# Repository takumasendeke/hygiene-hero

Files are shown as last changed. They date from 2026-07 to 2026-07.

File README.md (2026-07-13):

# Hygiene Hero 🫧
> "Making Clean Hands the Norm, Not the Exception"

Welcome to the official repository for **Hygiene Hero**, an interactive, behavior-driven embedded system designed to guide users through a proper 20-second handwashing routine recommended by WHO.

## Overview
Hand hygiene is a critical aspect of public health, yet global compliance rates remain incredibly low, with the average wash time sitting at just 6 seconds. Built as an open-source Electrical and Computer Engineering project at the University of Cape Town, Hygiene Hero tackles this behavioral shortfall. It utilizes multi-sensory feedback—including a visual countdown, animated graphics, and audio cues to encourage longer, proper handwashing and make the process engaging.

## Key Features
* **Touchless Activation:** Uses HC-SR04 ultrasonic sensors to monitor hand presence. 
* **Dynamic Visuals:** An ST7920 128x64 LCD plays custom, memory-optimized XBM animations directly from PROGMEM to save SRAM.
* **Clear Countdown:** A dual 7-segment display (driven by 74HC595 shift registers) provides an intuitive 20-second progress tracker.
* **Audio Nudges:** A DFPlayer Mini module plays background melodies and AI-generated vocal prompts over a UART interface.
* **Custom Enclosure:** A modular, 3D-printed housing designed in Onshape to protect the circuitry in a bathroom environment.

## Hardware Stack

| Component | Purpose |
| :--- | :--- |
| **Arduino Uno R3** | Master microcontroller orchestrating the state machine. |
| **ST7920 LCD (128x64)** | Renders handwashing animations and health facts via the U8g2 library. |
| **5161AS 7-Segment** | 2-digit display for the 20-second countdown. |
| **74HC595 Shift Registers** | Serial-to-parallel converters to drive the 7-segment display using minimal MCU pins. |
| **DFPlayer Mini + 8Ω Speaker** | Handles MP3 playback for background music and vocal cues. |
| **NE555D Timer** | Astable oscillator offloading the ultrasonic trigger pulse from the MCU. |
| **HC-SR04 / Tactile Button** | Inputs for proximity and soap detection. |

## Repository Structure

| Directory | Description |
| :--- | :--- |
| `/firmware` | Contains isolated subsystem prototypes and the final modular C++ source code (`src/` and `include/`). |
| `/hardware` | KiCad schematics, subcircuit experiments, and the final integrated PCB design. |
| `/enclosure` | CAD exports (STLs, STEPs) for the custom Bambu Lab 3D-printed housing. |
| `/docs` | Component datasheets, wiring diagrams, and project presentations. |

## Getting Started
1. Navigate to the `/firmware/prototypes` directory to view the isolated component tests for the display, audio, and sensors.
2. The final Object-Oriented system logic can be found in `/firmware/src/main.cpp`.
3. Ensure you have the `U8g2` and `DFRobotDFPlayerMini` libraries installed in your Arduino IDE or PlatformIO environment before compiling.

---
*Developed by Takudzwa Masendeke.*

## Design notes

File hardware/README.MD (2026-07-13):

# Hardware Design - Hygiene Hero 

Welcome to the hardware documentation for **Hygiene Hero**. This directory contains all Electronic Design Automation (EDA) files, chronicling the journey from initial proof-of-concept schematics to the final integrated Printed Circuit Board (PCB) ready for mass manufacturing.

## Hardware Architecture Overview
The Hygiene Hero hardware bridges standard microcontroller logic with custom analog and digital sub-systems. To optimize the Arduino Uno R3's (ATmega328P) processing load and pin count, the hardware specifically offloads tasks:
* **Hardware Triggering:** A 555 timer in astable mode continuously generates trigger pulses for the ultrasonic proximity sensors.
* **Serial-to-Parallel Conversion:** Daisy-chained 74HC595 shift registers drive the 2-digit 7-segment display using only 3 MCU pins.
* **Voltage Level Shifting:** A dedicated resistor network safely steps down the 5V TX logic to interface with the 3.3V RX line of the DFPlayer Mini.

## Directory Structure

| Directory | Description |
| :--- | :--- |
| `/main_board` | Contains the master KiCad project (`.pro`, `.sch`, `.kicad_pcb`). This is the final integrated custom PCB layout combining the MCU, audio, display, and sensor logic into a single, cohesive board. |
| `/subcircuits` | Holds the isolated schematics used during the breadboarding and prototyping phase (e.g., `Audio.kicad_sch`, `7 Seg Circuit.kicad_sch`, `Soap_water.kicad_sch`). These document the step-by-step engineering and debugging process. |
| `/production` | Contains the fabrication outputs required by PCB manufacturers. Includes Gerber files, NC Drill files, the Bill of Materials (BOM), and Component Placement Lists (CPL) for automated assembly. |

## Tools Used
* **EDA Software:** Designed and routed using [KiCad 10.0](https://www.kicad.org/).
* **Mechanical CAD:** The accompanying housing (found in the root `/enclosure` folder) was designed using Onshape.

## Viewing the Files
To open and edit the raw schematic and PCB files, you will need to install KiCad. Alternatively, PDF versions of the core schematics are provided within their respective folders for quick viewing without the EDA software.

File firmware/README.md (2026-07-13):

# Firmware - Hygiene Hero 

Welcome to the firmware documentation for **Hygiene Hero**. This directory houses the embedded C/C++ code that powers the system's state machine, audio handling, visual rendering, and sensor polling. 

## Software Architecture
The firmware for Hygiene Hero is built with a focus on memory optimization and modularity to operate efficiently on the 2KB SRAM constraint of the ATmega328P. 
* **Memory Management:** High-resolution display frames are converted to XBM format and stored entirely in Flash memory (`PROGMEM`) to prevent SRAM overflow.
* **Non-Blocking Logic:** The final system utilizes time-delta polling (`millis()`) rather than blocking `delay()` calls, allowing the MCU to multitask audio playback, display updates, and sensor reading simultaneously.
* **Object-Oriented Design:** The core logic is encapsulated into distinct C++ classes (`ShiftDisplay`, `AudioDeck`, `Sonar`) to ensure clean hardware abstraction and prevent variable scope conflicts.

## Directory Structure

| Directory | Description |
| :--- | :--- |
| `/prototypes` | Contains isolated "board bring-up" tests (e.g., `ultrasonic_test.ino`, `audio_Test.ino`). These standalone scripts were used to validate individual hardware subsystems and debug communication protocols prior to full system integration. |
| `/src` | Contains the final integrated C++ implementation files (`.cpp`), including the master state machine orchestrator (`main.cpp`). |
| `/include` | Contains the architectural blueprint headers (`.h`) for the OOP classes, defining the public interfaces and private hardware bindings. |

## Core Dependencies
To compile this firmware, ensure the following libraries are installed in your Arduino IDE or PlatformIO environment:
* **[U8g2](https://github.com/olikraus/u8g2):** For driving the ST7920 128x64 graphical display.
* **[DFRobotDFPlayerMini](https://github.com/DFRobot/DFRobotDFPlayerMini):** For UART control of the MP3 audio module.
* **SoftwareSerial:** Standard Arduino library used for virtual serial communication with the audio module.

## Compilation & Flashing
The final integrated code within `/src` is designed to be compiled using standard GCC toolchains or PlatformIO. If using the standard Arduino IDE, ensure the `.cpp` and `.h` files are located in a sketch folder named to match the primary `.ino` or `.cpp` file.

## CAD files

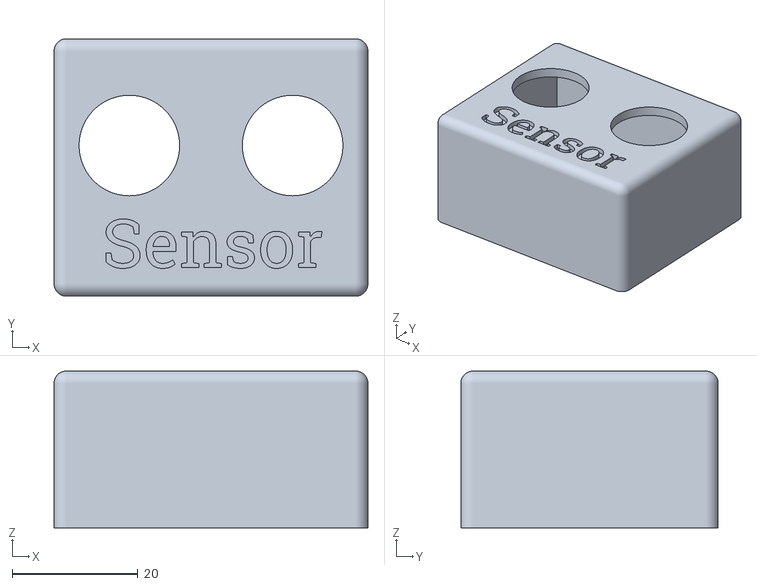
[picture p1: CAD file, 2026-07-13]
enclosure/CAD/sensor housing.stl
50.0 x 41.0 x 25.0

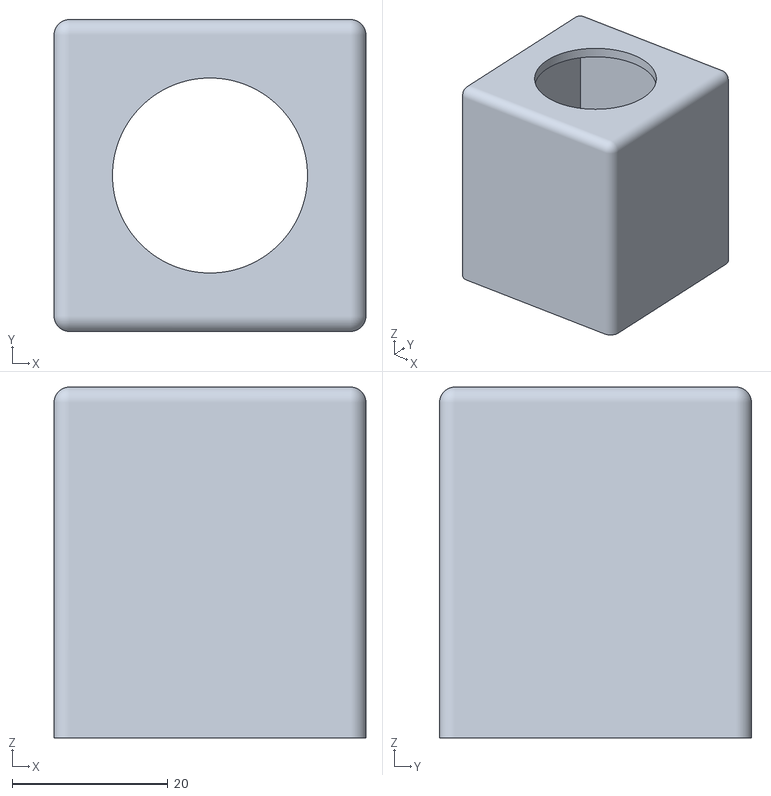
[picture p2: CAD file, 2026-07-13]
enclosure/CAD/button housing.stl
40.0 x 40.0 x 45.0

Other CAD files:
enclosure/3D print/Sensor & button housing.gcode.3mf

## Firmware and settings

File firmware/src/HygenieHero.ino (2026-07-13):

/*
Takudzwa Masendeke

This code is the main firmware for the Hygiene Hero Project.
It combines all the code from the prototyping to create the 
final system altogether.

HYGENIE HERO - v6.0

updates:
-added voice ques for actions
*/

#include "Components.h"
#include "Bitmaps.h"

// CONFIGURATION
const unsigned long IDLE_TRACK_MS  = 139000; // 2m 19s Song
const unsigned long SCRUB_MUSIC_MS = 25000; 
const unsigned long COME_BACK_MS   = 5000;  
const unsigned long ABANDON_TIMEOUT = 10000; 
const unsigned long SOAP_TIMEOUT    = 5000;  

// INSTANTIATE OBJECTS 
U8G2_ST7920_128X64_1_SW_SPI u8g2(U8G2_R0, 13, 11, 10, 12);
ShiftDisplay timer(5, 6, 7);   
AudioDeck voice(8, 9);         
Sonar hands(3, 4, 20.0);       

const uint8_t BTN_PIN = 2;

// VARIABLES
enum State { IDLE, WET, SOAP, SCRUB };
State currentState = IDLE;

// Animation
const uint8_t frames_per_step[] = { 8, 8, 67, 30, 30, 8 };
const int NUM_STEPS = 6;
int current_anim_step = 0;
int frame_idx = 0;
unsigned long lastTime = 0;

// Audio & Logic
unsigned long lastAudioTrigger = 0;
unsigned long currentTrackDuration = 4000;

// TIMERS
unsigned long handsLostTimer = 0;
unsigned long handsFoundTimer = 0;
unsigned long cooldownTimer = 0;
unsigned long soapPhaseStart = 0; 

bool isPaused = false;
bool hasPlayedPauseAudio = false;

// HELPER FUNCTIONS
void setTrackDuration(int trackNum) {

    switch(trackNum) {
        case 1: currentTrackDuration = IDLE_TRACK_MS; break;
        case 2: currentTrackDuration = 3000; break;
        case 3: currentTrackDuration = 3000; break;
        case 4: currentTrackDuration = SCRUB_MUSIC_MS; break;
        case 8: currentTrackDuration = COME_BACK_MS; break;
        default: currentTrackDuration = 4000; break;
    }
}

void playTrackSafe(int trackNum) {
    voice.playTrack(trackNum);
    setTrackDuration(trackNum);
    lastAudioTrigger = millis();
}

void resetToIdle() {
    // clear timer immediately
    timer.show(-1); 

    // short delay to let the last "Clean" audio finish slightly
    delay(2000);

    // reset state variables
    currentState = IDLE;
    timer.show(20);
    playTrackSafe(1); // Start Main Song
    cooldownTimer = millis(); 
    isPaused = false;
    handsLostTimer = 0;
    handsFoundTimer = 0;
    
    // force a screen update immediately so "Please Wash" appears now
    drawScreen(0, 0); 
}

// SETUP
void setup() {
  timer.begin();
  voice.begin();
  hands.begin();
  pinMode(BTN_PIN, INPUT_PULLUP);
  
  u8g2.begin();
  
  timer.show(20); 
  playTrackSafe(1); 
  cooldownTimer = millis(); 
}

// LOOP
void loop() {
  unsigned long now = millis();
  bool sensorActive = hands.isTriggered(); 

  // AUDIO WATCHDOG 
  if (!isPaused && (now - lastAudioTrigger > currentTrackDuration)) {
      if (currentState == IDLE) playTrackSafe(1); 
      else if (currentState == WET) playTrackSafe(2);
      else if (currentState == SOAP) playTrackSafe(3); 
      else if (currentState == SCRUB && current_anim_step == 2) playTrackSafe(4); 
  }

  // STATE MACHINE
  switch (currentState) {
    case IDLE:
      drawScreen(0, 0); 
      
      // cooldown check
      if (now - cooldownTimer < 2000) { 
          break; 
      }

      // easy trigger
      if (sensorActive) {
          currentState = WET;
          current_anim_step = 0; frame_idx = 0;
          playTrackSafe(2); 
      }
      break;

    case WET:
      runAnimation();
      if (frame_idx >= frames_per_step[0]) {
        currentState = SOAP;
        current_anim_step = 1; frame_idx = 0;
        playTrackSafe(3); 
        soapPhaseStart = now; 
      }
      break;

    case SOAP:
      runAnimation();
      if (frame_idx >= frames_per_step[1]) frame_idx = 0; 
      
      // soap timeout (5s)
      if (now - soapPhaseStart > SOAP_TIMEOUT) {
          resetToIdle();
          return;
      }

      // button wait (1.5s)
      if (now - soapPhaseStart > 1500) {
          if (digitalRead(BTN_PIN) == LOW) {
            currentState = SCRUB;
            current_anim_step = 2; frame_idx = 0;
            isPaused = false;
            handsLostTimer = 0;
            playTrackSafe(4); 
          }
      }
      break;

    case SCRUB:
      if (current_anim_step == 2) { 
          if (!sensorActive) {
              handsFoundTimer = 0;
              if (handsLostTimer == 0) handsLostTimer = now;
              
              // abandon timeout (10s)
              if (now - handsLostTimer > ABANDON_TIMEOUT) {
                  resetToIdle(); 
                  return;
              }

              // pause logic (1.5s)
              if (now - handsLostTimer > 1500) { 
                  isPaused = true;
                  if (!hasPlayedPauseAudio) {
                      playTrackSafe(8); 
                      hasPlayedPauseAudio = true;
                  }
                  drawScreen(0, 0); 
                  return; 
              }
          } else {
              handsLostTimer = 0;
              if (isPaused) {
                  if (handsFoundTimer == 0) handsFoundTimer = now;
                  if (now - handsFoundTimer > 500) { 
                      isPaused = false;
                      hasPlayedPauseAudio = false;
                      playTrackSafe(4); 
                  } else {
                      drawScreen(0, 0);
                      return; 
                  }
              }
          }
      }
      
      runAnimation();
      
      if (current_anim_step == 2) {
         int total = frames_per_step[2];
         int timeLeft = ((total - frame_idx) * 300) / 1000;
         if (timeLeft < 0) timeLeft = 0;
         timer.show(timeLeft); 
      } else {
         timer.show(-1);
      }

      if (frame_idx >= frames_per_step[current_anim_step]) {
        frame_idx = 0;
        current_anim_step++;
        
        if (current_anim_step == 3) playTrackSafe(5); 
        else if (current_anim_step == 4) playTrackSafe(6); 
        else if (current_anim_step == 5) playTrackSafe(7); 
        
        if (current_anim_step >= NUM_STEPS) {
          resetToIdle(); // trigger idle screen
        }
      }
      break;
  }
}

void runAnimation() {
  if (millis() - lastTime > 300) {
    lastTime = millis();
    u8g2.firstPage();
    do {
      if (current_anim_step < NUM_STEPS) {
          u8g2.drawXBMP(0, 0, 128, 64, bitmapSteps[current_anim_step][frame_idx % 2]);
      }
    } while (u8g2.nextPage());
    frame_idx++;
  }
}

void drawScreen(int step, int frame) {
  u8g2.firstPage();
  do {
    u8g2.setFont(u8g2_font_ncenB10_tr);
    u8g2.setDrawColor(1);
    u8g2.setFontPosTop();

    if (currentState == IDLE) {
        u8g2.drawStr(10, 0, "Please Wash");
        u8g2.drawStr(15, 16, "Your Hands");
        u8g2.setFont(u8g2_font_6x10_tf);
        u8g2.drawStr(0, 38, "80% of diseases");
        u8g2.drawStr(0, 50, "spread by touch");
    } 
    else if (currentState == SCRUB && isPaused) {
        u8g2.drawStr(10, 20, "Come Back!");
        u8g2.drawStr(5, 40, "Finish Scrub");
    }
  } while (u8g2.nextPage());
}

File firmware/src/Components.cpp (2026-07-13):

#include "Components.h"

// ===========================================================
//  CLASS 1: SHIFT DISPLAY (7-SEGMENT DRIVER)
// ===========================================================

ShiftDisplay::ShiftDisplay(uint8_t latch, uint8_t clock, uint8_t data) {
  _latch = latch;
  _clock = clock;
  _data = data;
}

void ShiftDisplay::begin() {
  pinMode(_latch, OUTPUT);
  pinMode(_clock, OUTPUT);
  pinMode(_data, OUTPUT);
}

void ShiftDisplay::show(int num) {
  byte tens, units;

  // Find hex code values in decimal
  if (num < 0) {
    // display blank in num is negative (0x00)
    tens = _digits[10];
    units = _digits[10];
  } else {
    // future proofing the firmware to allow timer changes up to 99
    // limit to 99 (two 7 segs) 
    if (num > 99) num = 99;
    
    // extract digits
    tens = _digits[num / 10];
    units = _digits[num % 10];
  }

  // shift them out
  // tens first pushes through to Reg B, units stays in Reg A
  digitalWrite(_latch, LOW);
  shiftOut(_data, _clock, MSBFIRST, tens);
  shiftOut(_data, _clock, MSBFIRST, units);
  digitalWrite(_latch, HIGH);
}


// ===========================================================
//  CLASS 2: AUDIO DECK (DFPLAYER DRIVER)
// ===========================================================

AudioDeck::AudioDeck(uint8_t rx, uint8_t tx) {
  // dynamically create the serial object to save memory until needed
  _serial = new SoftwareSerial(rx, tx);
}

void AudioDeck::begin() {
  _serial->begin(9600);
  
  delay(2000); // 2s delay to allow DFPlayer to boot up

  if (_player.begin(*_serial)) {
    _player.volume(20);
    delay(500);
  }
}

void AudioDeck::playTrack(int track) {
  // disable loop mode 
  _player.disableLoop();
  delay(100);
  
  // play track
  _player.play(track);
}

void AudioDeck::loopTrack(int track) {
  // start playing the track
  _player.play(track);
  
  // DELAY: Wait 600ms for the file to actually start loading
  // Clones are slow. If we send "Loop" too fast, they ignore it.
  delay(600); 
  
  // FORCE "Repeat Current" mode
  _player.enableLoop(); 
  delay(50);
  _player.enableLoop(); 
}

void AudioDeck::loopAll() {
  _player.enableLoopAll();
}


// ===========================================================
//  CLASS 3: SONAR (ULTRASONIC SENSOR)
// ===========================================================

Sonar::Sonar(uint8_t trig, uint8_t echo, float thresh) {
  _trig = trig;
  _echo = echo;
  _thresh = thresh;
}

void Sonar::begin() {
  pinMode(_trig, OUTPUT);
  pinMode(_echo, INPUT);
}

bool Sonar::isTriggered() {
  // send 10us Pulse
  digitalWrite(_trig, LOW); 
  delayMicroseconds(2);
  digitalWrite(_trig, HIGH); 
  delayMicroseconds(10);
  digitalWrite(_trig, LOW);

  // read echo (timeout 25ms to prevent blocking)
  unsigned long duration = pulseIn(_echo, HIGH, 25000UL); 
  
  // handle timeout (no object)
  if (duration == 0) return false;

  // calculate distance (speed of sound = 343m/s -> ~58us/cm)
  float distance = duration / 58.0;

  // check threshold
  return (distance < _thresh);
}

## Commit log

2026-07-08 feat: added housing for button and ultrasonic sensor
    [Sensor & button housing.gcode.3mf]
2026-07-13 chore: update file structure and naming convention
    [Sensor & button housing.gcode.3mf]
2026-07-13 fix: updated typos in comments
    [7_seg_test.ino, ultrasonic_test.ino]
2026-07-13 feat: used the CD4015 shift registers to turn on 20 LEDs and behave as a timer
2026-07-13 feat: implemented a LERP algorithm to make an RGB LED transition smoothly
2026-07-13 feat: uploaded docs, sorted filing and a Hardware readme
    [Sensor & button housing.gcode.3mf]
2026-07-13 feat: uploaded CAD renders of housing
    [button housing.stl, sensor housing.stl]
